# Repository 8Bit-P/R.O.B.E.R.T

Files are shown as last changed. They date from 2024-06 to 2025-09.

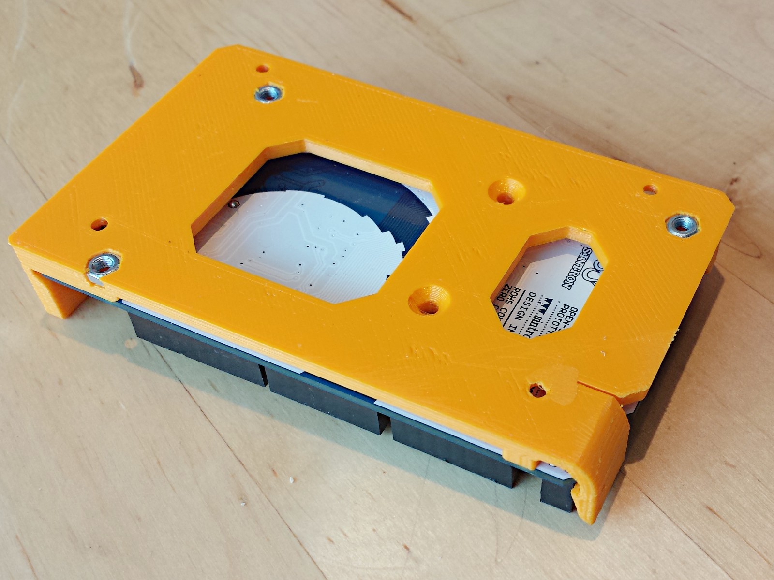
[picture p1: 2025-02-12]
HardwareAndDesigns/Case/Arduino Mega 2560 _ RAMPS Holder with Quick Release - 2165053/images/20170305_113625_.jpg

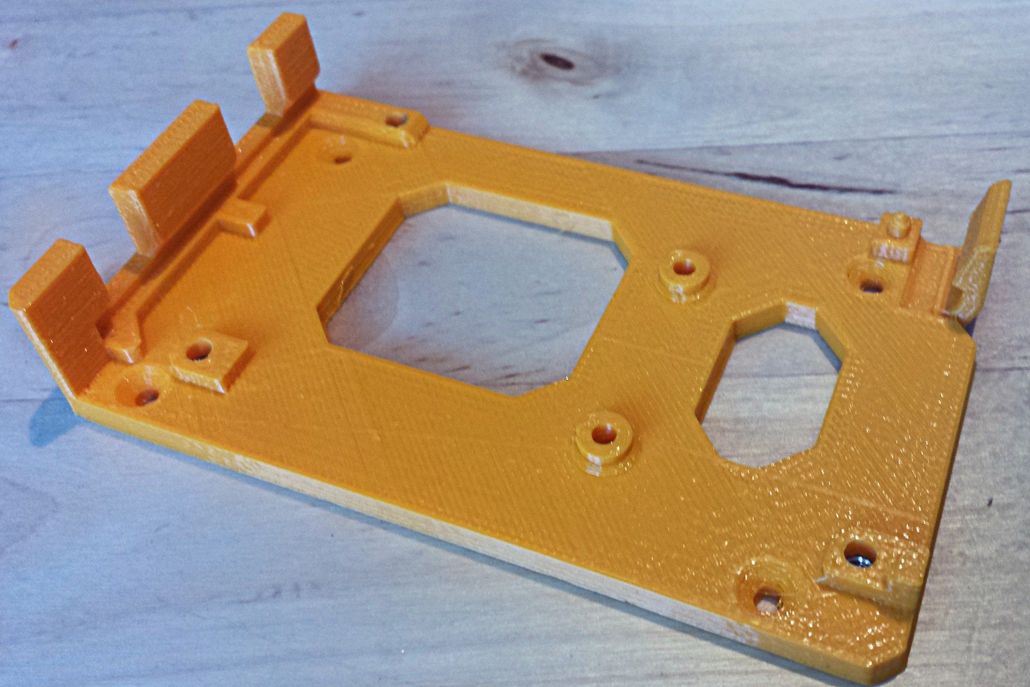
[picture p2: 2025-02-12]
HardwareAndDesigns/Case/Arduino Mega 2560 _ RAMPS Holder with Quick Release - 2165053/images/20170305_103735_.jpg

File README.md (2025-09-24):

# R.O.B.E.R.T 🤖  
*A 6-DOF robotic arm powered by Arduino + steppers, with a Tauri desktop app interface*  

  
  
  

---

## 📖 About the Project  

Meet **R.O.B.E.R.T.**, my DIY 6-DOF robotic arm project (currently running with 5 joints, gripper coming soon).  
It combines **hardware, electronics, and custom software** to create a full ecosystem for controlling a robotic arm.  

The project has three main parts:  

1. **Robotic Arm** – 3D printed + stepper motors for precise movements.  
2. **Electronics Box** – Arduino Mega 2560, RAMPS board, motor drivers, and power supply.  
3. **Desktop App** – Built with Tauri (Rust + React + Tailwind), it provides a clean UI to command the arm over a serial connection.  

---

## 🛠 Hardware  

The robotic arm has 6 joints, each powered by stepper motors. A gripper can be added to the end of J6 for more control. 

Electronics box components:  
- ⚡ Power supply (200W)  
- 🌀 TB6600 stepper motor driver for stepper 1
- 🧠 Arduino Mega 2560 + RAMPS board to manage steppers 2 to 6  
- 🎛️ Custom 3D-printed front panel for connectors
- 🔌 On/off switch + power input  

Each joint (except J6) has a **limit switch** for homing and preventing over-rotation.  
The overall build is made using a 3d printer for most of the parts of the robot, a bunch of nuts and bolts of different m-sizes, bearings and aluminum tube for structure. 

---

## 💻 Software  

The PC communicates with the Arduino via **serial connection**, structured into three abstraction layers:  

1️⃣ **Arduino firmware**  
   - Interprets serial commands  
   - Handles stepper movement, calibration, velocity, and acceleration  

2️⃣ **Desktop App (Tauri)**  
   - UI: React + TailwindCSS + TypeScript  
   - Backend: Rust  
   - Minimalist design (inspired by *Nothing* + Bento grids)  
   - Clean interface for controlling movements without raw commands  

3️⃣ **Custom Instruction Set**  
   - Works like a simplified programming language  
   - Interpreted line by line  
   - Can script movements (e.g., move multiple joints at once, set speeds, calibrate)  

👉 Full ecosystem: **Arduino firmware → Desktop app → Instruction set scripting**  

---

## ⚙️ Technologies  

**Frontend**  
- ReactJS  
- TailwindCSS  
- TypeScript  
- Vite  

**Backend**  
- Tauri (Rust)  

---

## 🚀 Running the Project  

Clone the repo and install dependencies:  

```bash
git clone https://github.com/8Bit-P/R.O.B.E.R.T.git
cd R.O.B.E.R.T/Application/ROBERT-APP
npm install
```

Run the Tauri app locally:
```bash
npm run tauri dev
```

> ⚠️ Make sure [Tauri is set up](https://tauri.app/v1/guides/getting-started/prerequisites) on your system.  

---

## ⌨️ Commands (Arduino Firmware)  

All commands end with `~` for quicker parsing.  

Examples:  

```markdown
//Move command, moves one or more joints a fixed amount of steps
MOVE>JOINT_NSTEPS;
MOVE>J1_100;
MOVE>J1_-200;J2_300;

//Toggle command, enables or disables a stepper
TOGGLE>JOINT_STATE;
TOGGLE>J1_ENABLED;
TOGGLE>J2_DISABLED;J2_ENABLED;

//Connect command, returns a string if the CONNECTED if the connection was successful
CONNECT>

//Calibrate command, homes all steppers to position '0'
CALIBRATE>J1; 
CALIBRATE>J1;J2; 

//Set velocity of steppers
SETVEL>80; // 0-1000 range 

//Set acceleration of steppers
SETACC>10; // 0-1000 range

//Returns state of all steppers
//example: [STATE];J1_DISABLED;J2_ENABLED;J3_ENABLED;J4_ENABLED;J5_ENABLED;J6_ENABLED
STATE> 

//Returns tracked steps of all steppers
//example: [STEPS];J1_300;J2_UNKNOWN;J3_UNKNOWN;J4_UNKNOWN;J5_UNKNOWN;J6_UNKNOWN
STEPS>

//Returns the calibration state of each stepper
//example: [STATE];J1_0;J2_1;J3_0;J4_1;J5_1;J6_1;
CALSTATE>

//Returns the velocity and acceleration of the steppers
//example: [PARAMS];VEL_20;ACC_40;
PARAMS>//Move command, moves one or more joints a fixed amount of steps
MOVE>JOINT_NSTEPS;
MOVE>J1_100;
MOVE>J1_-200;J2_300;

//Toggle command, enables or disables a stepper
TOGGLE>JOINT_STATE;
TOGGLE>J1_ENABLED;
TOGGLE>J2_DISABLED;J2_ENABLED;

//Connect command, returns a string if the CONNECTED if the connection was successful
CONNECT>

//Calibrate command, homes all steppers to position '0'
CALIBRATE>J1; 
CALIBRATE>J1;J2; 

//Set velocity of steppers
SETVEL>80; // 0-1000 range 

//Set acceleration of steppers
SETACC>10; // 0-1000 range

//Returns state of all steppers
//example: [STATE];J1_DISABLED;J2_ENABLED;J3_ENABLED;J4_ENABLED;J5_ENABLED;J6_ENABLED
STATE> 

//Returns tracked steps of all steppers
//example: [STEPS];J1_300;J2_UNKNOWN;J3_UNKNOWN;J4_UNKNOWN;J5_UNKNOWN;J6_UNKNOWN
STEPS>

//Returns the calibration state of each stepper
//example: [STATE];J1_0;J2_1;J3_0;J4_1;J5_1;J6_1;
CALSTATE>

//Returns the velocity and acceleration of the steppers
//example: [PARAMS];VEL_20;ACC_40;
PARAMS>
```

## ⌨️ Reduced Scripting Command Set

Used in the desktop app to give a set of instructions to reproduce for the arm.

```markdown
//Move command, moves one or more joints to a certain angle
MOVE>JOINT_ANGLE;
MOVE>J1_45;
MOVE>J1_90;J2_20;

//Toggle command, enables or disables a stepper
TOGGLE>JOINT_STATE;
TOGGLE>J1_ENABLED;
TOGGLE>J2_DISABLED;J2_ENABLED;

//Calibrate command, homes all steppers to position '0'
CALIBRATE>J1; 
CALIBRATE>J1;J2;J3;J4;J5;J6; 

//Set velocity of steppers
SETVEL>80; // 0-100 range 

//Set acceleration of steppers
SETACC>10; // 0-100 range

```

## 📜 License  

GNU License – feel free to fork, adapt, and improve!

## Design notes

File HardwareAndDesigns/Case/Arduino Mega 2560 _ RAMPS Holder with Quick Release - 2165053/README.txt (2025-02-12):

Arduino Mega 2560 / RAMPS Holder with Quick Release by BensHacks on Thingiverse: https://www.thingiverse.com/thing:2165053

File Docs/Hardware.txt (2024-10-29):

Steppers:

From www.omc-stepperonline.com models:
	17HS13-0404S-PG5 (Nema 17 with 5:1 planetary gearbox)
	14HR05-0504S (Round Nema 14 7Ncm)
	14HS08-0404S (Nema 14 5Ncm)
	17HS16-2004S1 (Nema 17 45Ncm) -

From banggood.com:
	Nema 17 (https://www.banggood.com/42mm-12V-Nema-17-Two-Phase-Stepper-Motor-For-3D-Printer-p-1164619.html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)
	Nema 8 (https://www.banggood.com/JKM-NEMA8-1_820-Hybrid-Stepper-Motor-Two-Phase-30mm-Motor-For-CNC-Mill-Router-p-980604.html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)

Limit switches:
	https://www.banggood.com/10Pcs-Micro-Limit-Switch-Roller-Lever-5A-125V-Open-Close-Switch-p-945733.html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 -

Pulleys and belts:
	GT2 16tooth (4pcs) -
	GT2 16tooth timing pulley without tooth (2pcs)
	GT2 6mm closed loop belts (- (solo 1 he comprado) 280mm 2pcs, 200mm 1pcs, - 158mm 1pcs) -
	HTD3 16T pulley
	HTD3 closed belt 330mm - 

Bearings:
	608 8x22x7 (2pcs) -
	625 5x16x5 (4pcs) -
	6002 15x32x9 (4pcs) -
	20X35X10 axial ball bearing (1pcs, originally used 2 but only needs one between stand and base) -

Bunch of nuts and bolts mainly m3 and m4 hex head (M8 bolts on the stand, base (for HTD3 tensioner bearings) and Arm2 mount)

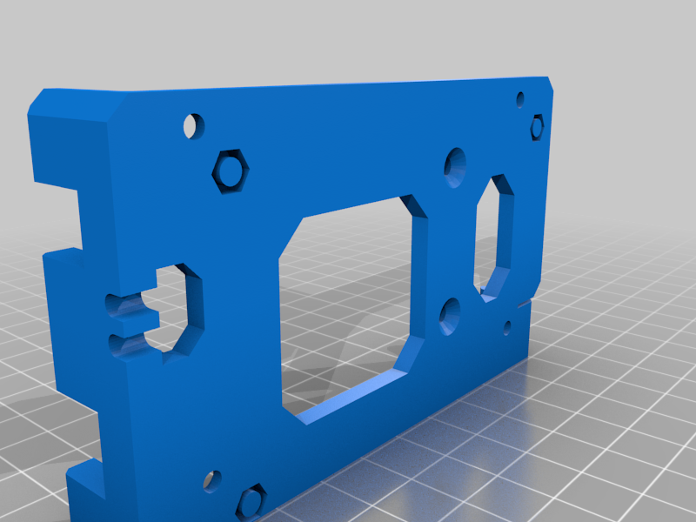
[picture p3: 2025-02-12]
HardwareAndDesigns/Case/Arduino Mega 2560 _ RAMPS Holder with Quick Release - 2165053/images/ba95177209f614d2fc3bdd85ac839c39.png

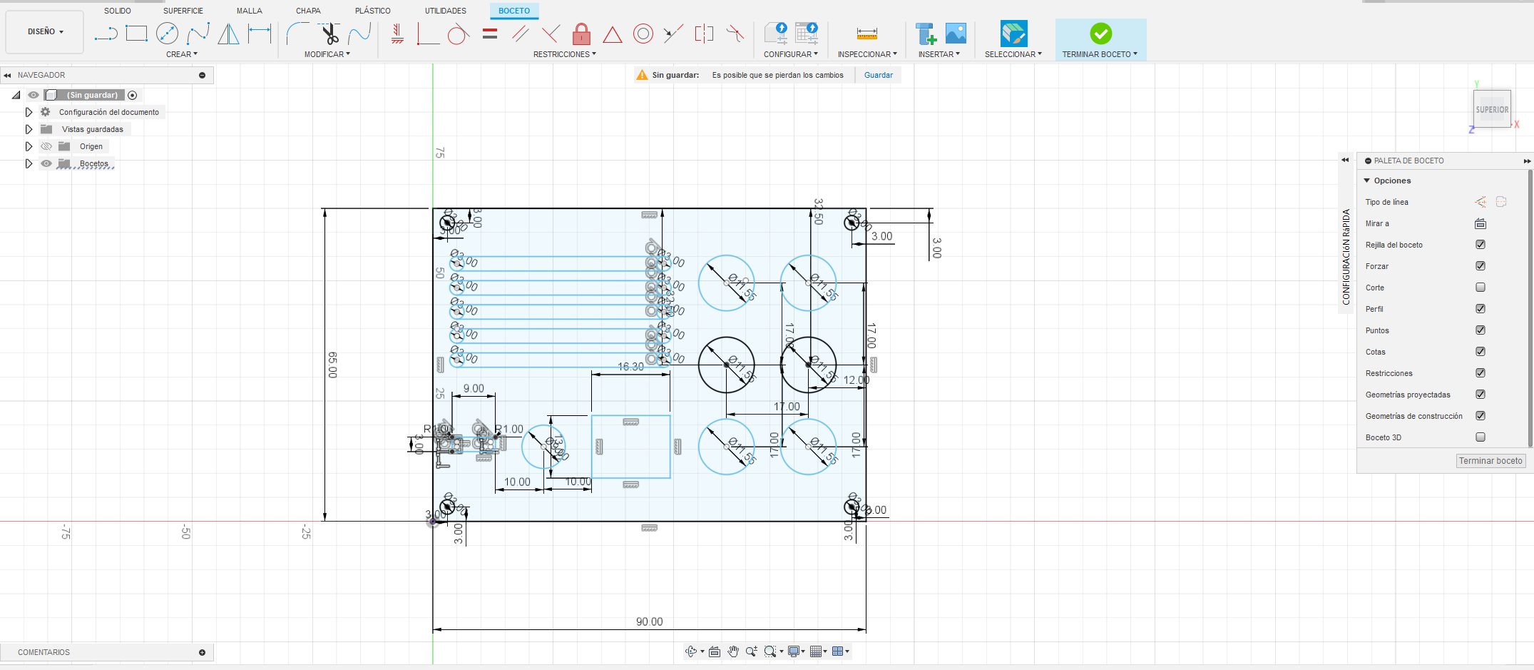
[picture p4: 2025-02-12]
Docs/ConnectorPannelDesign.png

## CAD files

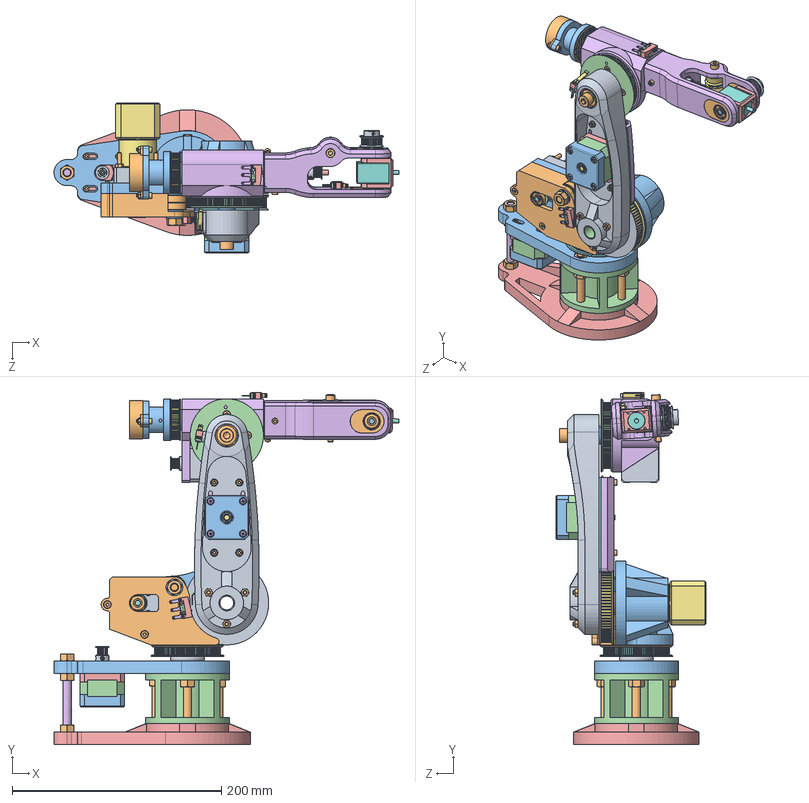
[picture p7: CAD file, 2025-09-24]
HardwareAndDesigns/Robot Solidworks model/Assem4_v2.SLDASM
329.5 x 336.5 x 142.9 mm
Arm1v2
socket head cap screw_iso x 47
Base x 2
Cuerpo x 2
Tapa x 2
pan cross head_am x 8
Eje x 2
instrument ball bearing_68_am x 4
GT2_16T_13x14 x 4
angular contact ball bearing_68_iso x 18
plain washer normal grade a_iso x 14
Pulley100Tv5
Toothless pulley 16t gt2 x 2
Arm 2.3
HTD3M 80T
Arm 4.3
HTD80T 2mm spacer
hex nut style 1 gradeab_iso x 30
100mm aluputki
90mm aluputki
15mm 1.6 rikka
Arm2Mountv2
Pulley60Tv2
15mm rikka 1.2mm
Nema 14 stepper
Nema 14 Round stepper
Motor 5 adapter
limit-switch-bottomcase x 4
limit-switch-top-case x 4
pins x 4
switch_lever x 4
Pulley100TBase
thrust ball bearing_68_iso x 2
Bottom spacer
Baseplate
Bottom Tube
Bottom support
hex bolt gradeab_iso
Nema 17 planetary 5 to 1 gearbox
HTD pulley adapter
Motor1 spacer
Basewall cover v2
BaseWall_2_v2
3M HTD 16T 6mm Bore
6mm akseli
Rotation arm V3
GT2 hihna chamfer rulla x 2
Nema8 Stepperi (banggood.com)
Pulley32TGT2
bearing adapter J6 housing x 2
5mm akseli 2
5mm akseli 1
J6 kotelo

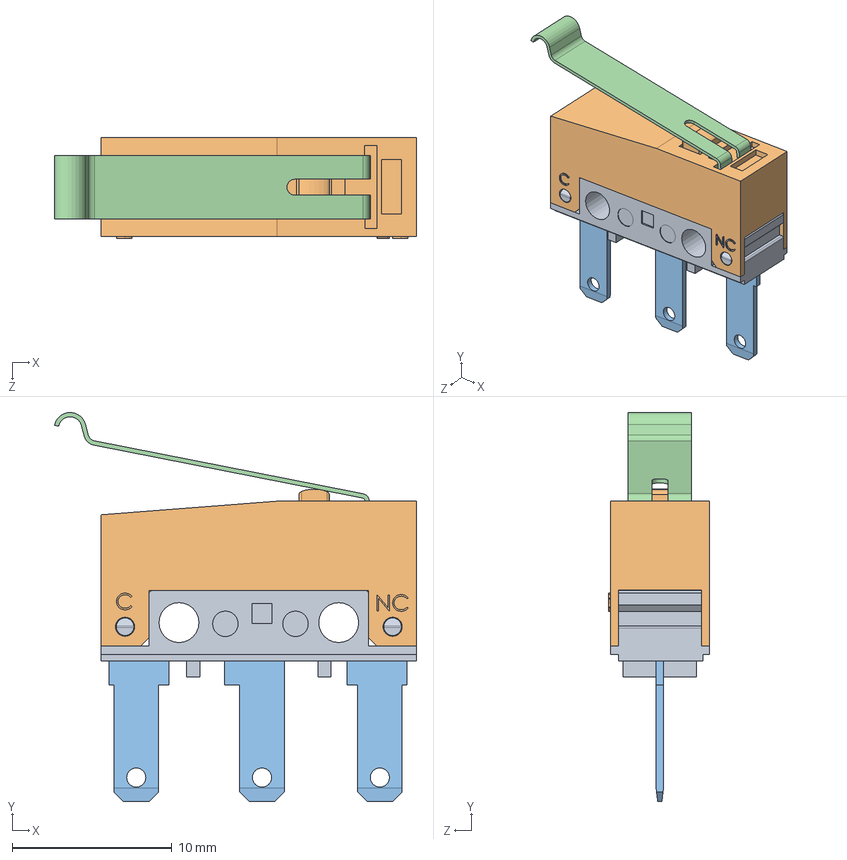
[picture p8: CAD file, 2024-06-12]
HardwareAndDesigns/Robot Solidworks model/microswitch-ss-3gl13sl-1.snapshot.2/Microswitch-SS-3GL13SL.SLDASM
22.7 x 24.4 x 6.30 mm
limit-switch-bottomcase
limit-switch-top-case
pins
switch_lever

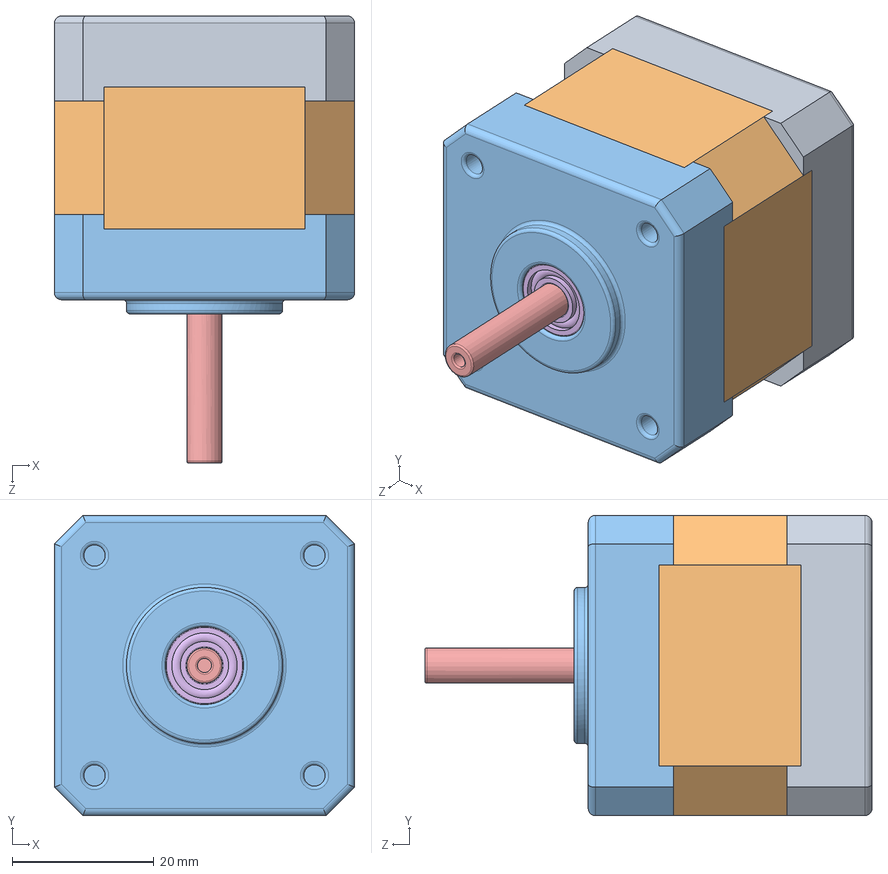
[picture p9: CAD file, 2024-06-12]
HardwareAndDesigns/Robot Solidworks model/stepper-motor-nema-17.snapshot.17/NEMA 17 kiinalaiset.SLDASM
42.3 x 42.3 x 63.0 mm
Base
Cuerpo
Tapa
pan cross head_am x 4
Eje
instrument ball bearing_68_am x 2

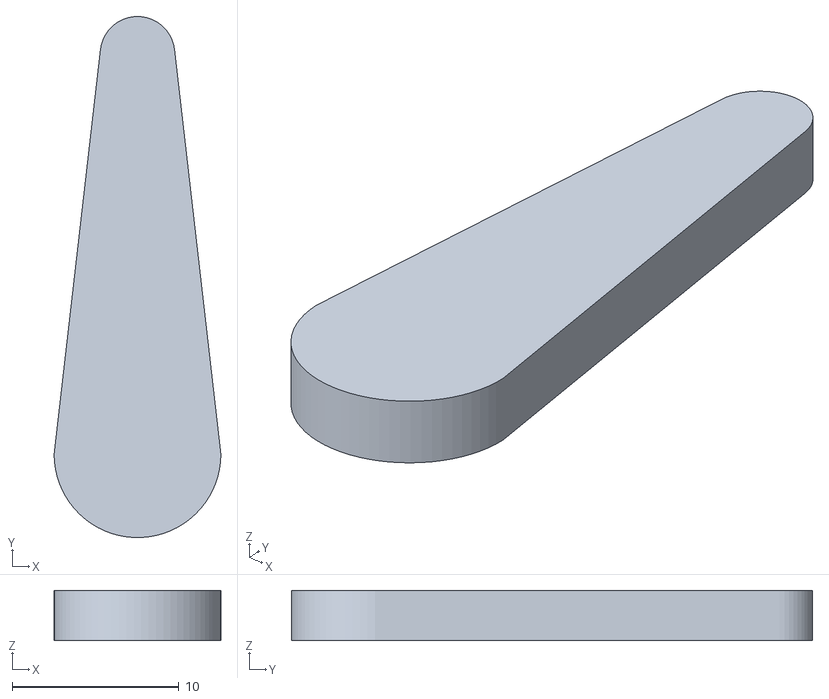
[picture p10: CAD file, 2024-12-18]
HardwareAndDesigns/Additional/BaseLimiter.stl
10.0 x 31.2 x 3.00

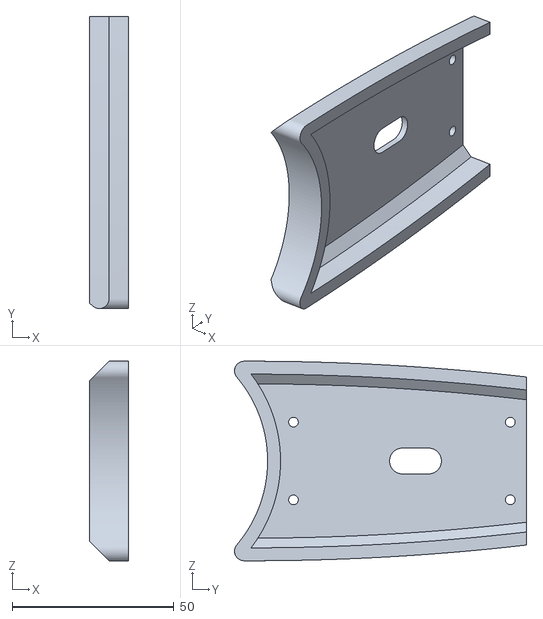
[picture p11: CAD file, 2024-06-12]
HardwareAndDesigns/Arm1/Arm 2.3.STL
12.0 x 90.2 x 61.7

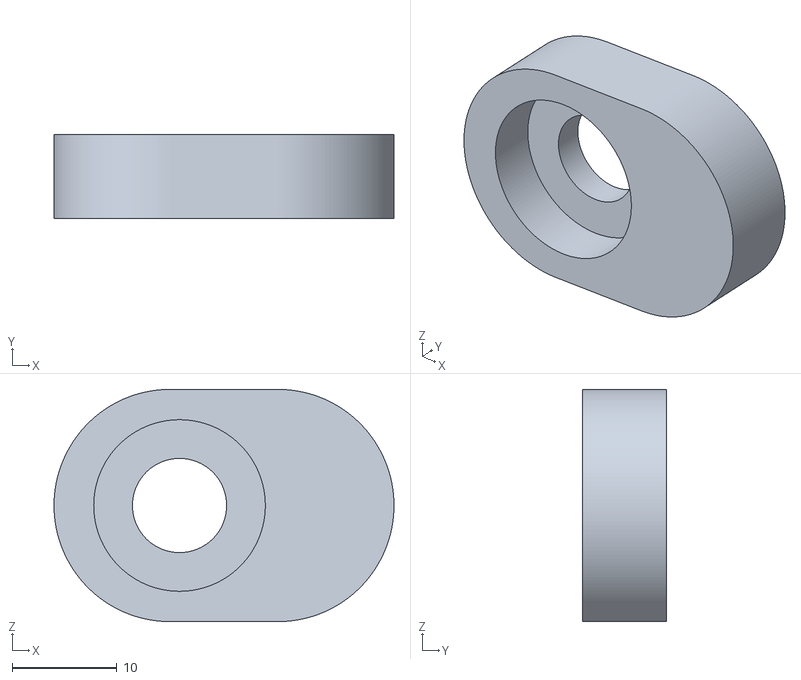
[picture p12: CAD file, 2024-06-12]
HardwareAndDesigns/Arm2/bearing adapter J6 housing.STL
32.5 x 8.00 x 22.2

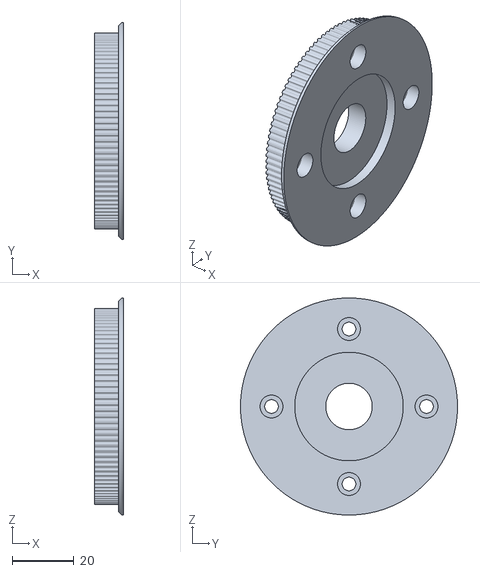
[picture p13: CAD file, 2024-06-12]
HardwareAndDesigns/Base/Pulley100TBase.STL
9.30 x 70.0 x 70.0

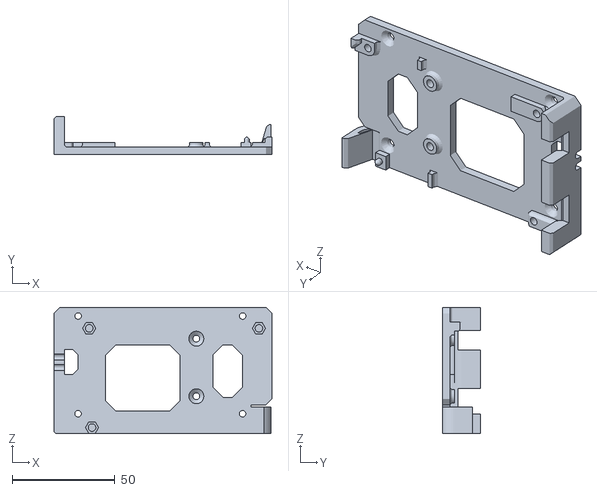
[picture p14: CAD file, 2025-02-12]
HardwareAndDesigns/Case/Arduino Mega 2560 _ RAMPS Holder with Quick Release - 2165053/files/RAMPS_Holder.stl
106.0 x 18.4 x 61.5

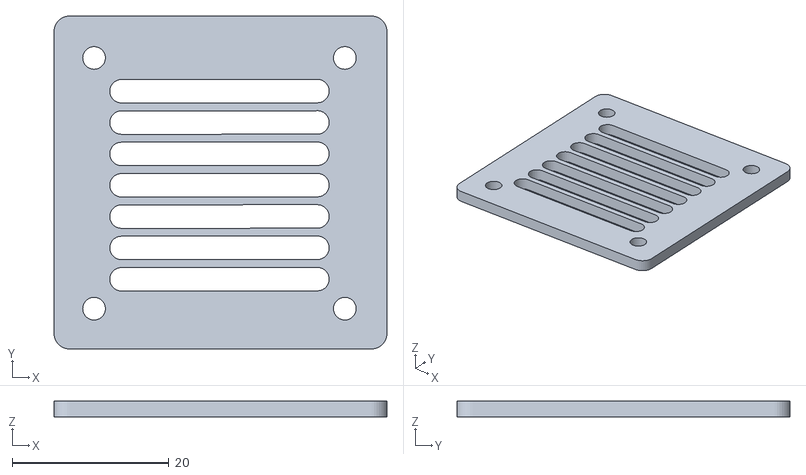
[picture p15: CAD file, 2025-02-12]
HardwareAndDesigns/Case/Ventilation_.stl
42.5 x 42.5 x 2.00

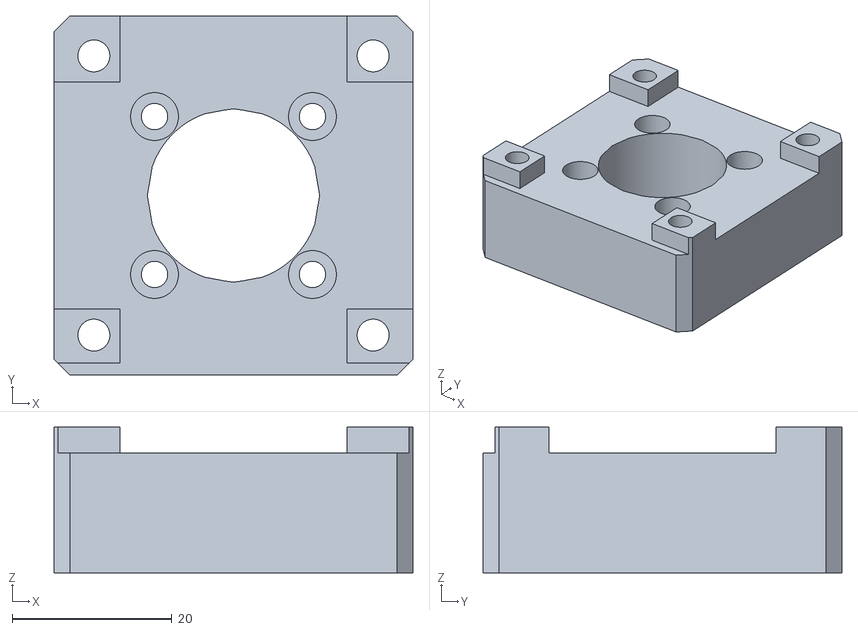
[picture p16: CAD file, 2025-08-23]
HardwareAndDesigns/PiecesRework/ReductorSeparatorNoGapAndMoreSeparation.stl
45.0 x 45.0 x 18.3

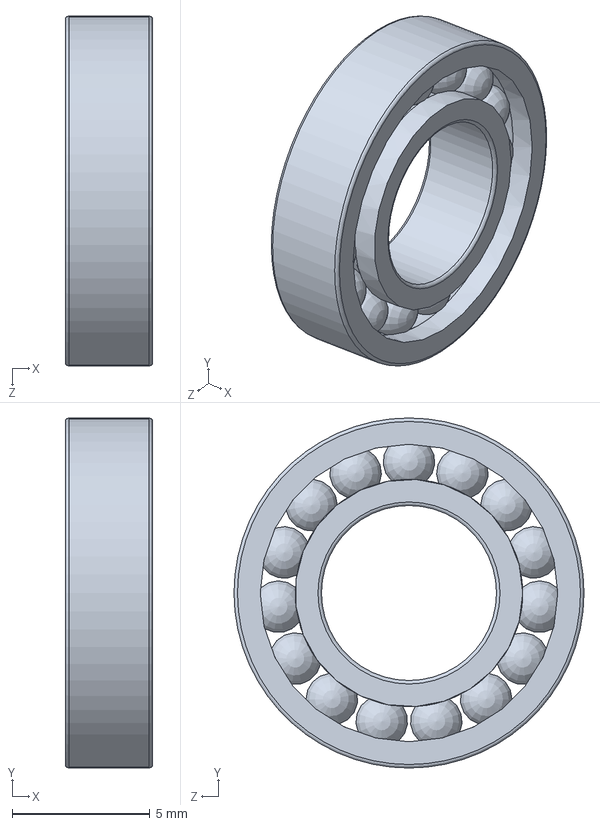
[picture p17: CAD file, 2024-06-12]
HardwareAndDesigns/Robot Solidworks model/ball bearings/instrument ball bearing_68_am.sldprt
3.17 x 12.7 x 12.7 mm

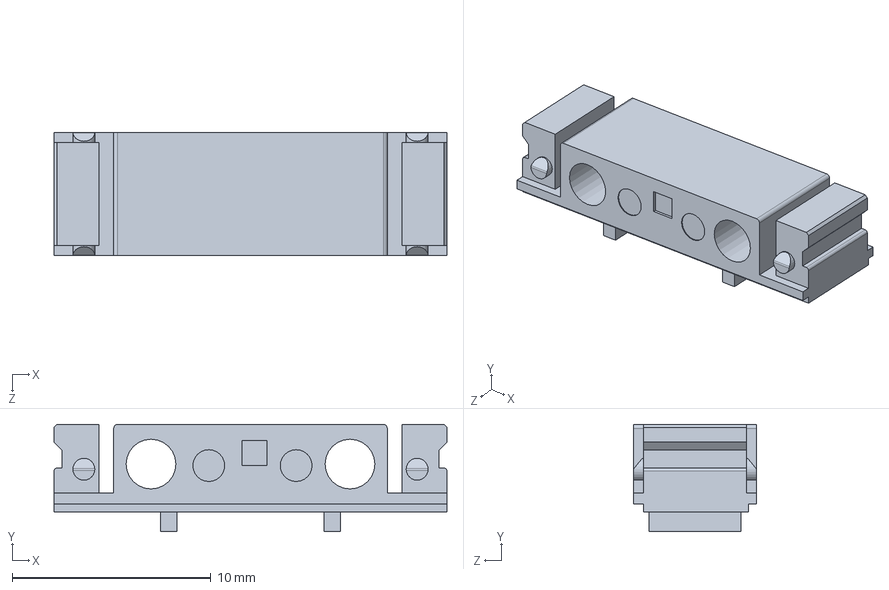
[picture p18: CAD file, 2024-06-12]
HardwareAndDesigns/Robot Solidworks model/microswitch-ss-3gl13sl-1.snapshot.2/limit-switch-bottomcase.SLDPRT
19.8 x 5.40 x 6.20 mm

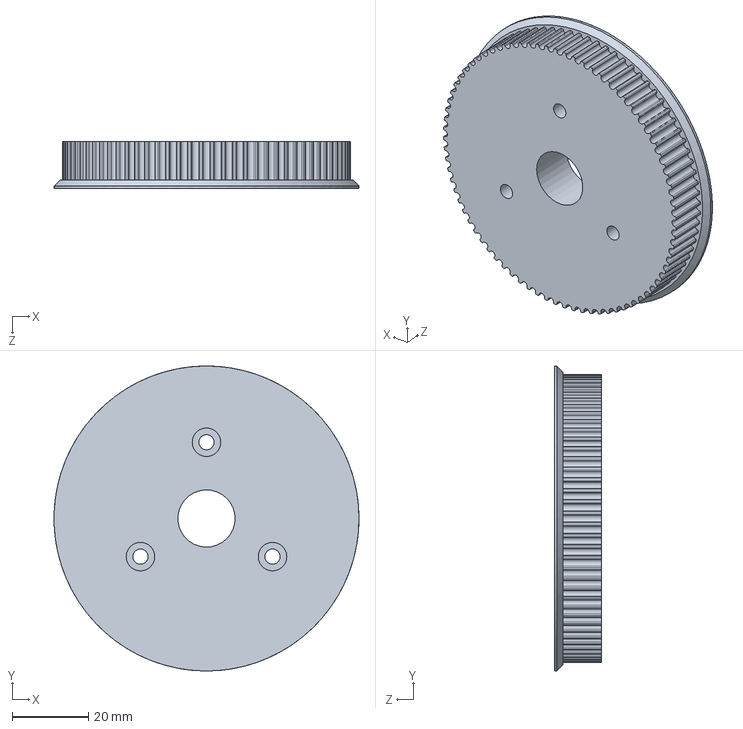
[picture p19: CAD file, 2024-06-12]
HardwareAndDesigns/Robot Solidworks model/Solidworks/HTD3M 80T.SLDPRT
80.0 x 80.0 x 12.4 mm

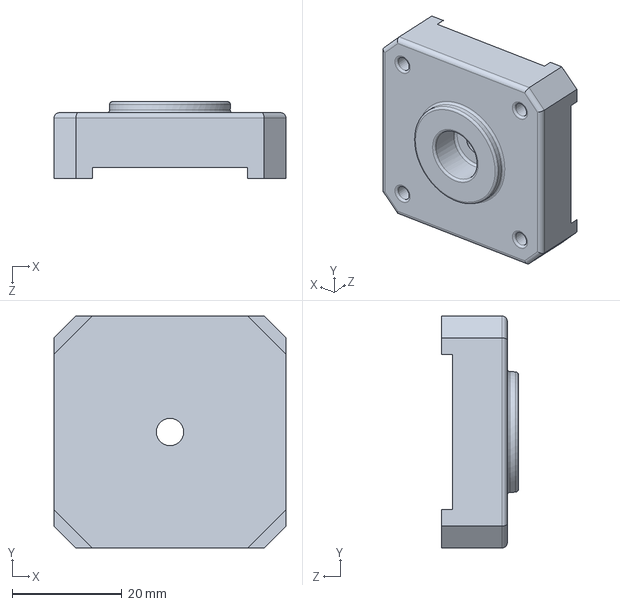
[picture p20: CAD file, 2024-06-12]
HardwareAndDesigns/Robot Solidworks model/stepper-motor-nema-17.snapshot.17/Tapa.SLDPRT
42.3 x 42.3 x 14.0 mm

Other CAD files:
HardwareAndDesigns/Robot Solidworks model/v.5/Motor 5 adapter.SLDPRT
HardwareAndDesigns/Stand/Baseplate.STL
HardwareAndDesigns/Additional/LimitSwitchBase.stl
HardwareAndDesigns/Arm1/HTD3M 80T.STL
HardwareAndDesigns/Arm1/Arm 4.3.STL
HardwareAndDesigns/Arm1/Arm1v2.STL
HardwareAndDesigns/Arm1/HTD80T 2mm spacer.STL
HardwareAndDesigns/Arm2/Arm2Mountv2.STL
HardwareAndDesigns/Arm2/GT2 belt chamfer roller.STL
HardwareAndDesigns/Arm2/J6 housing.STL
HardwareAndDesigns/Arm2/Motor 5 adapter.STL
HardwareAndDesigns/Arm2/Pulley100Tv5.STL
HardwareAndDesigns/Arm2/Pulley32TGT2.STL
HardwareAndDesigns/Arm2/Pulley60Tv2.STL
HardwareAndDesigns/Arm2/Rotation arm V3.STL
HardwareAndDesigns/Base/BaseWall_2_v2.STL
HardwareAndDesigns/Base/Basewall cover v2.STL
HardwareAndDesigns/Base/Motor1 spacer.STL
HardwareAndDesigns/Case/Base Top Half.stl
HardwareAndDesigns/Case/BottomPlate2.stl
HardwareAndDesigns/Case/Box.stl
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

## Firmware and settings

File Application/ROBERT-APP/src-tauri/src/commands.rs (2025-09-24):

use crate::state::SharedAppState;
use crate::utils::{connection_utils, ik_utils, parameter_utils, stepper_utils};
use tauri::{AppHandle, State};

#[tauri::command]
pub async fn connect_to_port<'a>(port: String, state: State<'a, SharedAppState>) -> Result<String, String> {
    connection_utils::connect_to_port(port, state).await
}

#[tauri::command]
pub fn get_ports() -> Vec<String> {
    return connection_utils::get_ports_list()
}

#[tauri::command]
pub async fn disconnect_from_active_connection<'a>(state: State<'a, SharedAppState>) -> Result<String, String> {
    return connection_utils::disconnect(state.inner()).await
}

#[tauri::command]
pub async fn set_acceleration<'a>(acceleration: i8, state: State<'a, SharedAppState>) -> Result<String, String> {
    return parameter_utils::set_acceleration(acceleration, state.inner().clone()).await
}

#[tauri::command]
pub async fn set_velocity<'a>(velocity: i8, state: State<'a, SharedAppState>) -> Result<String, String> {
    return parameter_utils::set_velocity(velocity, state.inner().clone()).await
}

#[tauri::command]
pub async fn get_parameters<'a>(state: State<'a, SharedAppState>) -> Result<[u8; 2], String> {
    return parameter_utils::get_parameters(state.inner().clone()).await
}

#[tauri::command]
pub async fn toggle_stepper<'a>(joint_index: i8, enabled: &str, state: State<'a, SharedAppState>) -> Result<String, String> {
    return stepper_utils::toggle_stepper(joint_index, enabled, state.inner().clone()).await
}

#[tauri::command]
pub async fn calibrate_steppers<'a>(joints_indexes: Vec<i8>, state: State<'a, SharedAppState>) -> Result<String, String> {
    return stepper_utils::calibrate_steppers(joints_indexes, state.inner().clone()).await
}

#[tauri::command]
pub async fn check_steppers_state<'a>(state: State<'a, SharedAppState>) -> Result<[bool; 6], String> {
    return stepper_utils::get_steppers_state(state.inner().clone()).await;
}

#[tauri::command]
pub async fn move_step<'a>(app: AppHandle, joint_index: i8, n_steps: i16, state: State<'a, SharedAppState>) -> Result<String, String> {
    return stepper_utils::move_step(&app, joint_index, n_steps, state.inner().clone()).await
}

//Command assumes all joint angles are provided as positive numbers
#[tauri::command]
pub async fn drive_steppers_to_angles<'a>(app: AppHandle, joints_angles: Vec<(i8, f32)>, state: State<'a, SharedAppState>) -> Result<String, String> {
    return stepper_utils::drive_steppers_to_angles(&app, joints_angles, state.inner().clone()).await
}

#[tauri::command]
pub async fn get_steppers_angles<'a>(app: AppHandle, state: State<'a, SharedAppState>) -> Result<[Option<f32>; 6], String> {
    return stepper_utils::get_steppers_angles(&app, state.inner().clone()).await;
}

#[tauri::command]
pub async fn get_fk_from_angles(app: AppHandle, state: State<'_, SharedAppState>) -> Result<[f32; 6], String> {
    return ik_utils::get_robot_transform_from_angles(&app, state.inner().clone()).await
}

#[tauri::command]
pub async fn get_angles_from_ik(end_effector_transform: [f32; 6],app: AppHandle, state: State<'_, SharedAppState>) -> Result<[f32; 6], String> {
    return ik_utils::get_angles_from_end_effector_transform(end_effector_transform,&app, state.inner().clone()).await
}

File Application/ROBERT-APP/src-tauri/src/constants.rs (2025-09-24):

use once_cell::sync::Lazy;
use std::collections::HashMap;

use crate::structs::{angles::AngleLimits, dh_parameters::DHParameters};

// Command Codes
pub struct CommandCodes;

impl CommandCodes {
    pub const MOVE: &'static str = "MOVE>";
    pub const CHECK: &'static str = "CHECK>";
    pub const SETVEL: &'static str = "SETVEL>";
    pub const SETACC: &'static str = "SETACC>";
    pub const TOGGLE: &'static str = "TOGGLE>";
    pub const CALIBRATE: &'static str = "CALIBRATE>";
    pub const STATE: &'static str = "STATE>";
    pub const STEPS: &'static str = "STEPS>";
    pub const PARAMS: &'static str = "PARAMS>";
}

// Response Codes
pub struct ResponseCodes;

impl ResponseCodes {
    pub const CONNECTED_RESPONSE: &'static str = "CONNECTED";
    pub const CALIBRATION_RESPONSE: &'static str = "[CALIBRATION];";
    pub const STATE_RESPONSE: &'static str = "[STATE];";
    pub const STEPS_RESPONSE: &'static str = "[STEPS];";
    pub const PARAMS_RESPONSE: &'static str = "[PARAMS];";
}

// Error Codes (as a HashMap for easy lookup by code)
pub static ERROR_CODES: Lazy<HashMap<&'static str, &'static str>> = Lazy::new(|| {
    let mut m = HashMap::new();
    m.insert("C001", "Command was not properly formatted");
    m.insert("C002", "Command not defined");
    m.insert("I001", "Invalid stepper");
    m.insert("I002", "Invalid stepper state");
    m.insert("I003", "Invalid limit switch conversion");
    m
});

// Joint Reduction Ratios (as a HashMap where key = Joint ID, value = reduction ratio as a float)
pub static JOINT_REDUCTIONS: Lazy<HashMap<u8, f32>> = Lazy::new(|| {
    let mut m = HashMap::new();
    m.insert(1, 100.0 / 16.0);
    m.insert(2, 80.0 / 16.0);
    m.insert(3, 100.0 / 16.0);
    m.insert(4, 60.0 / 16.0);
    m.insert(5, 32.0 / 16.0);
    m.insert(6, 1.0 / 1.0); //No reduction on gripper rotatation
    m
});

pub fn get_reduction_ratio(joint_id: u8) -> Option<f32> {
    JOINT_REDUCTIONS.get(&joint_id).copied()
}

// Joint angle limits: min and max per joint
pub static ANGLE_LIMITS: Lazy<HashMap<u8, AngleLimits>> = Lazy::new(|| {
    let mut m = HashMap::new();
    m.insert(1, AngleLimits { min: 0.0, max: 270.0 });
    m.insert(2, AngleLimits { min: -15.0, max: 75.0 });
    m.insert(3, AngleLimits { min: -70.0, max: 50.0 });
    m.insert(4, AngleLimits { min: 0.0, max: 270.0 });
    m.insert(5, AngleLimits { min: 0.0, max: 45.0 });
    // J6 has no limits, so it's not added
    m
});

pub fn get_max_angles(joint_id: u8) -> Option<AngleLimits> {
    ANGLE_LIMITS.get(&joint_id).copied()
}

pub static DEGREES_PER_STEP: Lazy<HashMap<u8, f32>> = Lazy::new(|| {
    let mut m = HashMap::new();
    m.insert(1, 1.8);
    m.insert(2, 0.35);
    m.insert(3, 1.8);
    m.insert(4, 1.8);
    m.insert(5, 0.9);
    m.insert(6, 1.8);
    m
});

pub fn get_degrees_per_step(joint_id: u8) -> Option<f32> {
    DEGREES_PER_STEP.get(&joint_id).copied()
}

lazy_static::lazy_static! {
    pub static ref STEPPER_POSITIVE_TO_LIMIT: HashMap<u8, bool> = {
        let mut map = HashMap::new();
        map.insert(1, false); //E.g this means stepper 1 when given positive steps it drives away from the limit switch
        map.insert(2, false);
        map.insert(3, true);
        map.insert(4, true);
        map.insert(5, false); // TODO: Set when joints build
        map.insert(6, false);
        map
    };
}

//Velocity and acceleration "sensitivity"
pub const PARAMETERS_MULTIPLIER: u8 = 10;

//TODO: GRIPPER PARAMETERS MISSING
// DH Parameters for the 6-DOF robotic arm
pub static DH_TABLE: Lazy<[DHParameters; 6]> = Lazy::new(|| {
    [
        DHParameters { theta: 0.0, d: 43.66, a: 37.866, alpha: -90.0_f32.to_radians() }, // Joint 1
        DHParameters { theta: -90.0_f32.to_radians(), d: 0.0, a: 160.0848, alpha: 0.0 },  // Joint 2
        DHParameters { theta: 180.0_f32.to_radians(), d: 0.0, a: 0.0, alpha: 90.0_f32.to_radians() },   // Joint 3
        DHParameters { theta: 0.0, d: 140.0, a: 0.0, alpha: -90.0_f32.to_radians() },    // Joint 4
        DHParameters { theta: 0.0, d: 0.0, a: 0.0, alpha: 90.0_f32.to_radians() },      // Joint 5
        DHParameters { theta: 0.0, d: 36.0, a: 0.0, alpha: 0.0 },                         // Joint 6
    ]
});

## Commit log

2024-06-29 Testing Script for arduino
2024-06-29 Arduino script and more WPF progress
2024-06-30 Functional simple controller for arduino
2024-10-29 Old files
    [100mm aluputki.SLDPRT, 15mm 1.6 rikka.SLDPRT, 15mm rikka 1.2mm.SLDPRT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]
2024-11-08 Added connection to Arduino by serial
2024-11-10 Test files for case
    [Box.stl, Electronics Box 180mmx130mmx60mm.SLDPRT, ReductorSeparator.stl]
2024-11-24 Implemented velocity and acceleration commands in backend and calls from react frontend
2024-12-12 Fix on errors and toasters
    [SerialController.ino, commands.rs]
2024-12-13 Improved response time from Arduino
2024-12-13 Toggle command implemented on application (Arduino still not implemented)
2024-12-13 Fixes on toggle command
    [SerialController.ino, commands.rs]
2024-12-14 Stl files for limit switches
    [BaseLimiter.stl, LimitSwitchBase.stl]
2024-12-14 Implemented Calibration on React
    [Box.stl]
2024-12-14 Calibration useffect frontend
2024-12-17 Divided Arduino logic into different files
2024-12-17 Fix bugs on modularization
    [CommandProcessor.cpp, SerialController.ino, StepperManager.cpp]
2024-12-17 Fixed bug on connection and implemented simple calibration
    [CommandProcessor.cpp, Constants.h, SerialController.ino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]
2024-12-18 Some fixes on Arduino calibration and calibration command from tauri
    [CommandProcessor.cpp, Constants.h, StepperManager.cpp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]
2024-12-18 Array implementation of stepper motors
2024-12-19 Connector pannel file
    [ConnectorPannel.stl]
2024-12-21 Added new constant error in tauri
    [constants.rs]
2025-01-30 3D files
    [Base Top Half.stl, BottomPlate2.stl, ConnectorPannel v5.stl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]
2025-02-09 Small testing changes on arduino script
2025-02-09 Limit pin error
2025-02-09 Arduino positive and negative steps
2025-02-09 Change stepper 1 behaviour on enable
2025-02-09 Constants and minor modifications
    [USBc v1.stl, Ventilation_.stl]
2025-02-09 STATE command on arduino
2025-02-10 Stepper context, drive_steppers_to_angles and drive_steppers_to_angles (not completed)
2025-02-12 Arduino STEPS and STATE commands separated
2025-02-12 Fixed J5 gear ration
    [constants.rs]
2025-02-13 Calibration timeout, improved connection and disconnection,
2025-02-13 StepperContext for angles, states and calibration
2025-02-13 Automatic Enable Stepper
2025-02-14 Always positive angles and steps to move steppers
2025-02-16 Fix in acc and vel fetch
    [commands.rs]
2025-02-22 Multi-stepper movement
2025-02-22 Event listening for steppers angles
2025-02-23 Timeout duration as a parameter on arduino commands
2025-03-20 Fix frontend calibration
2025-03-20 Disable buttons on disconnect
2025-03-29 Bugfixing in code runner
    [StepperManager.cpp]
2025-08-23 Markdown for the project
    [ReductorSeparatorNoGapAndMoreSeparation.stl]
2025-09-11 Refactor and calibrate all fix
    [100mm aluputki.SLDPRT, 15mm 1.6 rikka.SLDPRT, 15mm rikka 1.2mm.SLDPRT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]
2025-09-14 Start of forward kinematics
2025-09-15 FK implementation and simulation (still buggy)
    [ROBERT.blend]
2025-09-17 Refactor relative angles
    [ROBERT.blend]
2025-09-19 Semi-working FK
    [ROBERT.blend]
2025-09-19 Adjusted model to be centered on J1
    [ROBERT.blend]
